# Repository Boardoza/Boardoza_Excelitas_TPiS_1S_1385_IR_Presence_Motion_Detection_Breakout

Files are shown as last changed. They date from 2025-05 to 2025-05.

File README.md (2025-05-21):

# Boardoza Excelitas TPiS 1S 1385 High-Sensitivity Presence Sensor Breakout Board

The **Boardoza Excelitas TPiS 1S 1385** is a compact and ultra-low-power **infrared presence and motion detection breakout board** based on the **Excelitas TPiS 1S 1385** thermopile sensor. Designed for **non-contact presence sensing**, this module integrates a high-sensitivity thermopile with a **120° field of view**, ideal for motion-triggered lighting, smart occupancy detection, and thermal monitoring in energy-efficient IoT systems.

It features an **I²C interface** (default address: 0x0C), integrated digital signal processing, and a dedicated **interrupt pin** for presence, movement, and temperature threshold events. With just **15µA of typical current draw**, the TPiS 1S 1385 is an ideal solution for battery-powered and energy-sensitive applications.

## [Click here to purchase!](https://www.ozdisan.com/maker-ve-iot-urunleri/boardoza/boardoza-modulleri/BOARDOZA-TPIS1385/1473945)

|Front Side|Back Side|
|:---:|:---:|
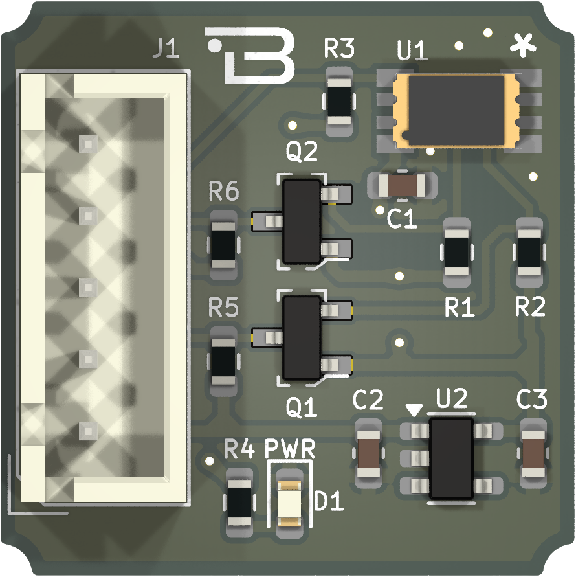
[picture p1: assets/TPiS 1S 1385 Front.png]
Front
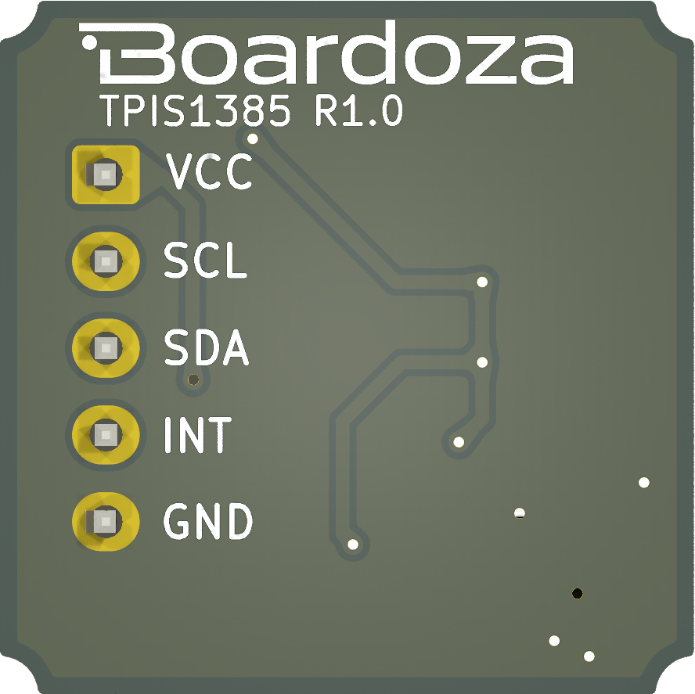
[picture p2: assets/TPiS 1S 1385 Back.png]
Back
| | |

---

## Key Features

- **High-Sensitivity Infrared Thermopile:** Designed for non-contact presence, motion, and temperature detection.
- **120° Field of View:** Wide-area sensing coverage for smart automation and ambient detection.
- **Digital Signal Processing:** Onboard 50 µW processing engine filters noise and enhances reliability.
- **Low Power Consumption:** Ultra-low 15µA supply current for long-lasting operation.
- **I²C Interface:** Communicates easily with MCUs (default address: 0x0C).
- **Interrupt Functionality:** Dedicated interrupt pin triggers alerts for configurable motion and thermal thresholds.

---

## Technical Specifications

**Model:** Excelitas TPiS 1S 1385  
**Input Voltage:** 3.3V – 5V  
**Supply Current:** 15µA (typical)  
**Functions:** High-Sensitivity Presence and Motion Sensor  
**Communication:** I²C (Default Address: 0x0C)  
**Field of View:** 120°  
**Operating Temperature:** -20°C ~ +85°C  
**Board Dimensions:** 20mm x 20mm  

---

## **Board Pinout**

| Pin Number | Pin Name | Description |
|:---:|:---:|---|
| 1 | VCC | Positive Power Supply (3.3V–5V) |
| 2 | SCL | I²C Serial Clock Input |
| 3 | SDA | I²C Serial Data |
| 4 | INT | Interrupt Output |
| 5 | GND | Ground |

---

## Board Dimensions

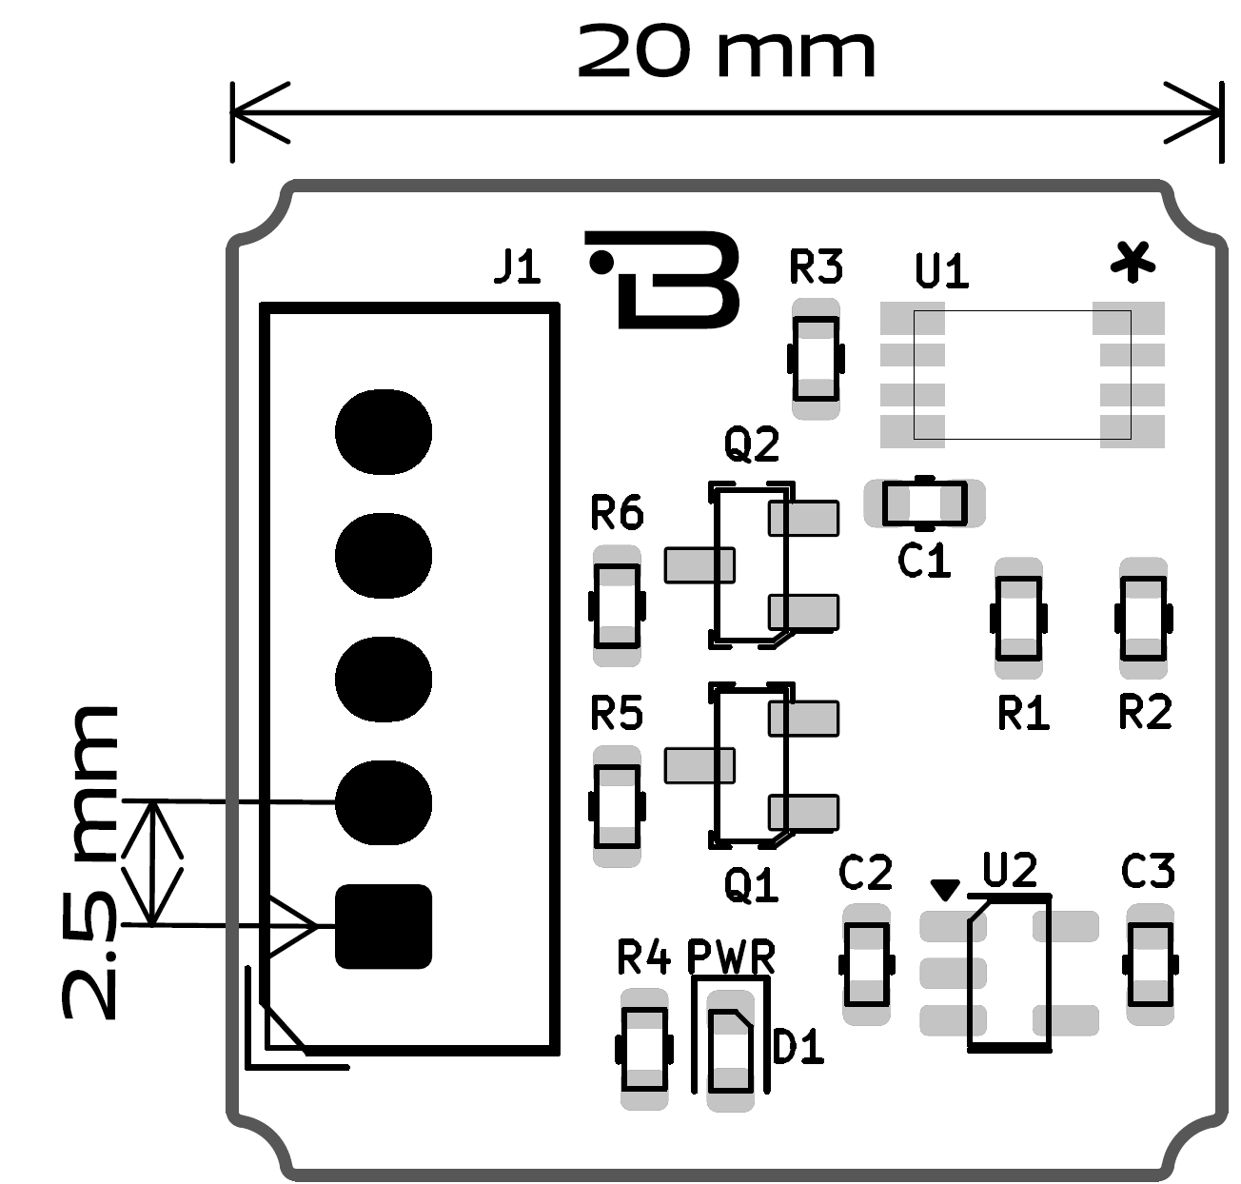
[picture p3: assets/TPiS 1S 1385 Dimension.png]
Board Dimensions


---

## Step Files

[Boardoza TPiS_1S_1385.step](./assets/TPiS%201S%201385%20Step.step)

---

## Datasheet

[TPiS_1S_1385 Datasheet.pdf](.)

---

## Version History

- V1.0.0 - Initial Release

---

## Support

- If you have any questions or need support, please contact <support@boardoza.com>

---

## License

Shield: [][cc-by-sa]

This work is licensed under a [Creative Commons Attribution-ShareAlike 4.0 International License][cc-by-sa].

[][cc-by-sa]

[cc-by-sa]: http://creativecommons.org/licenses/by-sa/4.0/
[cc-by-sa-image]: https://licensebuttons.net/l/by-sa/4.0/88x31.png
[cc-by-sa-shield]: https://img.shields.io/badge/License-CC%20BY--SA%204.0-lightgrey.svg

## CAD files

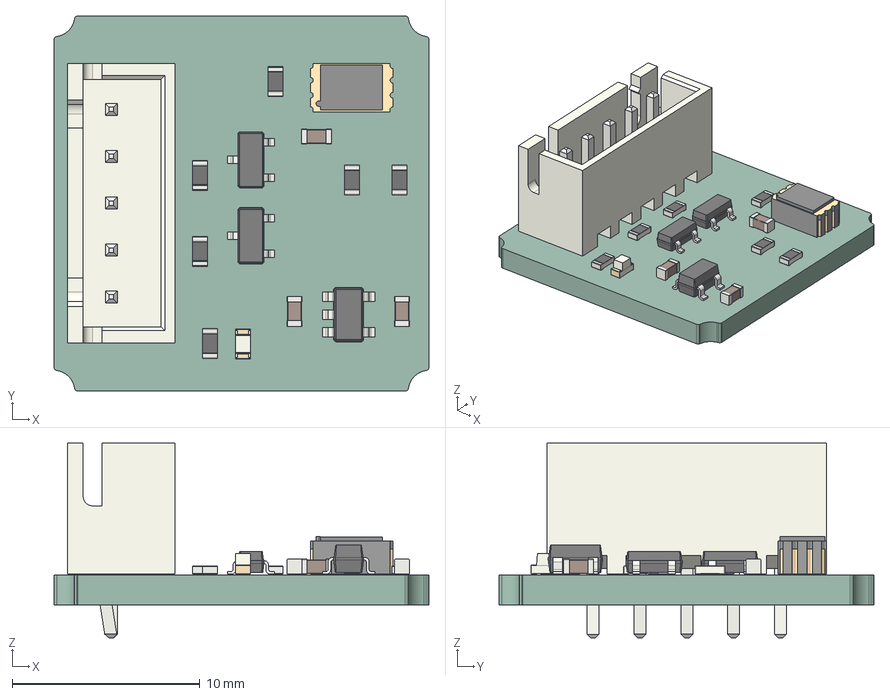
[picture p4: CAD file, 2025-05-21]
assets/TPiS 1S 1385 Step.step
20.0 x 20.0 x 10.4 mm
C_0603_1608Metric x 3
R_0603_1608Metric x 6
SOT_23 x 2
SOT_23_5
JST_B5B_XH_A
LED_0603_1608Metric
TPIS 1S 1385
_autosave-B-TPÄ°S1385-BRK_PCB

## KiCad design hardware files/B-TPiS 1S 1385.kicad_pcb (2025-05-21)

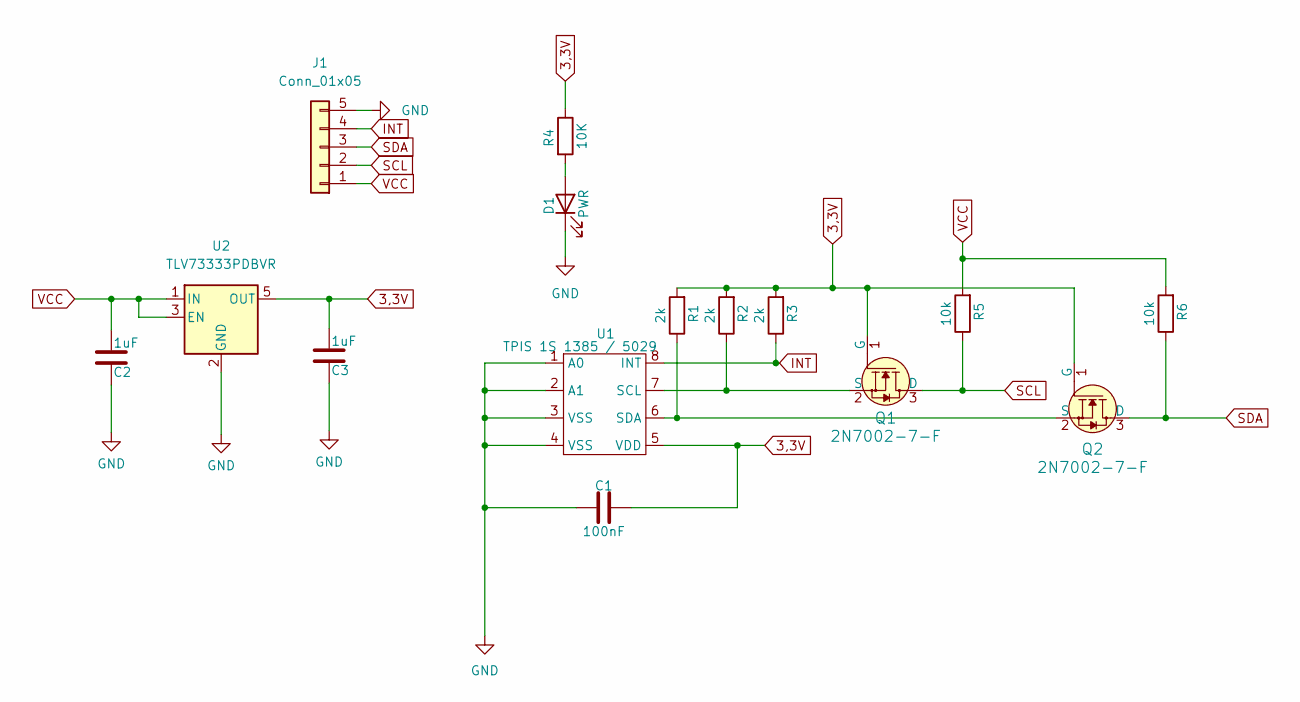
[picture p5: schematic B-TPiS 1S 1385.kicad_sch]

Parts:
C1: 100nF; C_0603_1608Metric; MPN CL10B104KB8NNNC
C2, C3: 1uF; C_0603_1608Metric; MPN CL10A105KO8NNNC
D1: PWR; LED_0603_1608Metric; MPN 19-213USRC/S259/TR8
J1: Conn_01x05; 2317-05S_1x05_P2.50mm_Vertical
Q1, Q2: 2N7002-7-F; SOT-23-3; MPN 2N7002_R1_00001
R1, R2, R3: 2k; R_0603_1608Metric; MPN 0603SAJ0202T5E
R4: 10K; R_0603_1608Metric; MPN 0603SAJ0103T5E
R5, R6: 10k; R_0603_1608Metric; MPN 0603SAJ0103T5E
U1: TPIS 1S 1385 / 5029; Temperature SensorSMD; MPN TPIS 1S 1385 / 5029
U2: TLV73333PDBVR; SOT-23-5; MPN TLV73333PDBVR

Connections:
3,3V: C1.2, C3.1, Q1.1 (G), Q2.1 (G), R1.2, R2.2, R3.2, R4.1, U1.5 (VDD), U2.5 (OUT)
GND: C1.1, C2.1, C3.2, D1.1 (K), J1.5, U1.1 (A0), U1.2 (A1), U1.3 (VSS), U1.4 (VSS), U2.2 (GND)
INT: J1.4, R3.1, U1.8 (INT)
unnamed: D1.2 (A), R4.2
unnamed: Q1.2 (S), R2.1, U1.7 (SCL)
unnamed: Q2.2 (S), R1.1, U1.6 (SDA)
SCL: J1.2, Q1.3 (D), R5.1
SDA: J1.3, Q2.3 (D), R6.1
VCC: C2.2, J1.1, R5.2, R6.2, U2.1 (IN), U2.3 (EN)

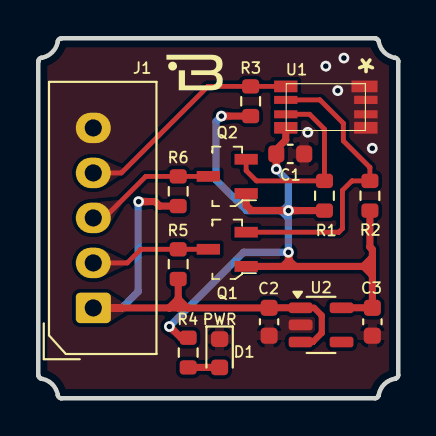
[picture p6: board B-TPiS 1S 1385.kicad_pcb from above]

Board: 2 copper layers, 20.0 x 20.0 mm, 15 parts (0 on the bottom side), 9 nets.

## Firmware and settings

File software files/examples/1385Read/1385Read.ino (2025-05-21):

#include "caliPile.h"

const int interruptPin = 4;
uint8_t  intStatus = 0;
bool presSign = false, motSign = false;
caliPile sensor(interruptPin);

void inthandler() {
  newInt = true;
}

void setup() {
  Serial.begin(115200);

  Wire.begin();

  sensor.activateSensor();

  sensor.initMotion(LP_8s, LP_1s, src_TPOBJLP1_TPOBJLP2, ms30);

  sensor.TempCalculations();
  sensor.initTPotThreshHold(131); //0x83

  sensor.initTpMotionThreshHold(10);

  sensor.initTpPresenceThreshHold(30);
  attachInterrupt(digitalPinToInterrupt(interruptPin), inthandler, FALLING);  // define interrupt for INT pin output of CaliPile
}

void loop() {

  Serial.print(sensor.calcAmbientTemp(sensor.getAmbientTemp()));
  Serial.print("  ");
  Serial.print(sensor.calcObjectTemp(sensor.getObjectTemp(), sensor.calcAmbientTemp(sensor.getAmbientTemp())));
  Serial.println("  ");
  delay(100);
}
